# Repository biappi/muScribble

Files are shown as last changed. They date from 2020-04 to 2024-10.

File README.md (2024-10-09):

# µScribble

An hardware USB [Scribble Strip](https://www.sweetwater.com/insync/scribble-strip/)
 that supports the Mackie Control Protocol.

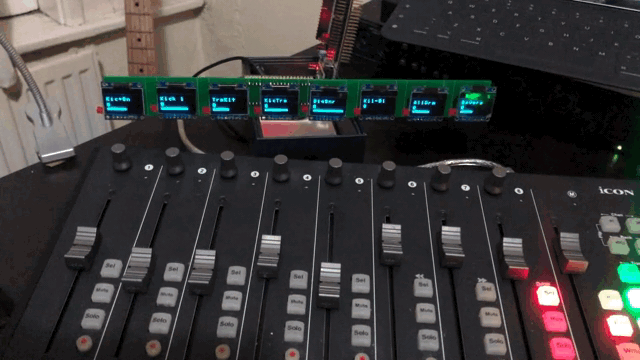
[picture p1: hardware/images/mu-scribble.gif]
µScribble in action


## Introduction

µScribble is an USB Midi gadget designed to be a companion to inexpensive faderboxes
without displays. It should be compatible with any DAW that supports control surfaces.
I've personally used it with [Apple Logic Pro](https://www.apple.com/logic-pro/) and
[Ableton Live](https://www.ableton.com/en/live/).

The hardware itself is very simple an d based around an
[STM32F4](https://www.st.com/en/microcontrollers-microprocessors/stm32f4-series.html)
evaluation board, sometimes known as "blackpill", while the displays are the SPI variant
of the ubiquitous [SSD1306 OLED screens](https://cdn-shop.adafruit.com/datasheets/SSD1306.pdf).

The software is implemented using the [unicore-mx](https://github.com/insane-adding-machines/unicore-mx)
fork of [libopencm3](https://github.com/libopencm3/libopencm3) as it has a slighlty
better support for the stm32 target platform. It should be relatively easy to port
the application code to any microcontroller of choice.

## Hardware design files

The hardware is designed using the [KiCad EDA](https://kicad.org)

* [KiCad project directory](hardware/kicad)
* [Schematic diagram PDF](hardware/images/schema.pdf)

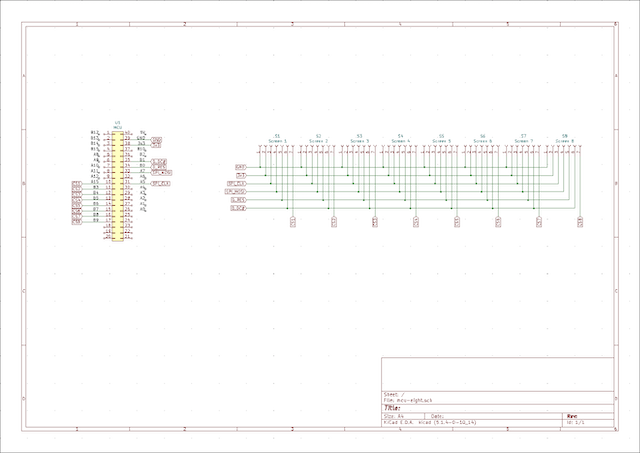
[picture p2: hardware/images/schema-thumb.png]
Schematic diagram thumbnail
  

* [Gerber fabrication files directory](hardware/gerbers)

  PCB diagram thumbnail

## Software

The firmware depends on the `arm-none-eabi-gcc` toolchain, and to compile it
it's sufficient to invoke

```
make
```

As a convenience, if you have the [STLink](https://github.com/stlink-org/stlink/)
tools installed, you can flash the firmware to the device using the `st-flash` command
with

```
make flash
```

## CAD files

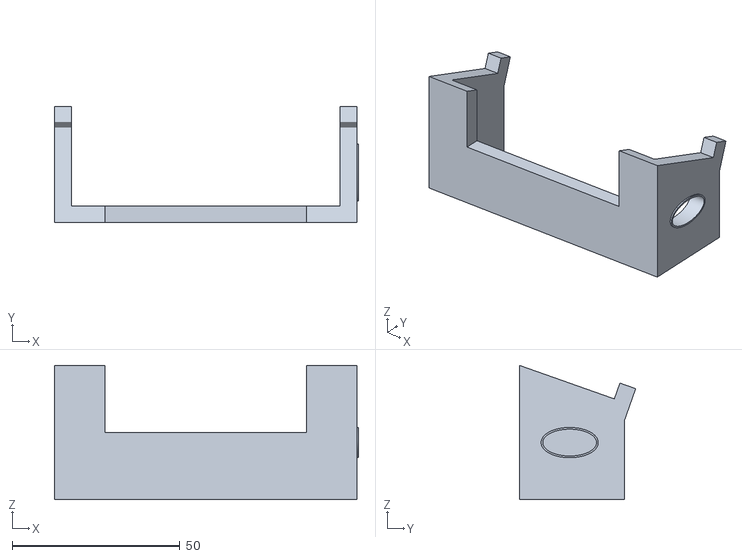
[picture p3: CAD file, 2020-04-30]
hardware/stl/holder.stl
90.5 x 34.7 x 40.0

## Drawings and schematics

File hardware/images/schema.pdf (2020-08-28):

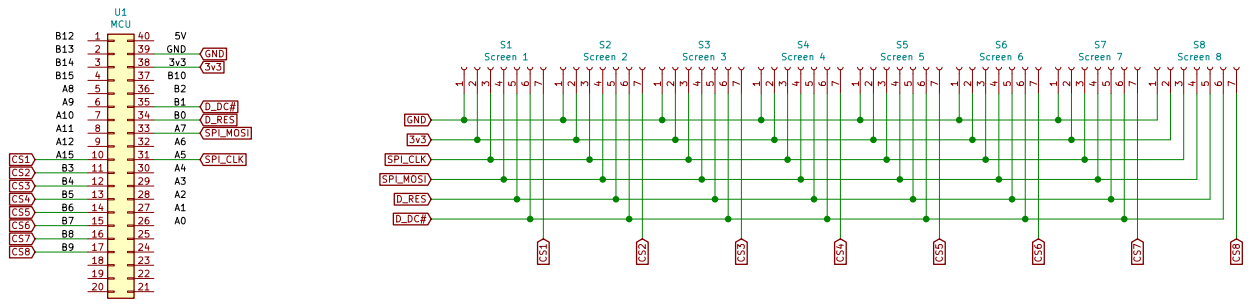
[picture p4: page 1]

File: mcu-eight.sch Sheet: /
Id: 1/1 Title:

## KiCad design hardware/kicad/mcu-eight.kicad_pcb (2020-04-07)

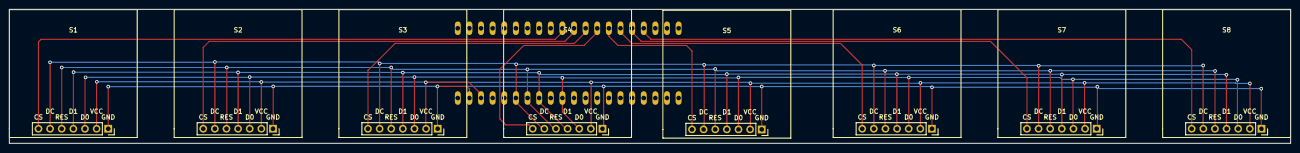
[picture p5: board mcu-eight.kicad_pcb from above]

Board: 2 copper layers, 280.0 x 29.3 mm, 9 parts (1 on the bottom side), 14 nets.

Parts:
S1: Screen 1; display-spi
S2: Screen 2; display-spi
S3: Screen 3; display-spi
S4: Screen 4; display-spi
S5: Screen 5; display-spi
S6: Screen 6; display-spi
S7: Screen 7; display-spi
S8: Screen 8; display-spi
U1: MCU; YAAJ_BohPill

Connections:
3v3: S1.2, S2.2, S3.2, S4.2, S5.2, S6.2, S7.2, S8.2, U1.38
CS1: S1.7, U1.10
CS2: S2.7, U1.11
CS3: S3.7, U1.12
CS4: S4.7, U1.13
CS5: S5.7, U1.14
CS6: S6.7, U1.15
CS7: S7.7, U1.16
CS8: S8.7, U1.17
D_DC#: S1.6, S2.6, S3.6, S4.6, S5.6, S6.6, S7.6, S8.6, U1.35
D_RES: S1.5, S2.5, S3.5, S4.5, S5.5, S6.5, S7.5, S8.5, U1.34
GND: S1.1, S2.1, S3.1, S4.1, S5.1, S6.1, S7.1, S8.1, U1.39
SPI_CLK: S1.3, S2.3, S3.3, S4.3, S5.3, S6.3, S7.3, S8.3, U1.31
SPI_MOSI: S1.4, S2.4, S3.4, S4.4, S5.4, S6.4, S7.4, S8.4, U1.33

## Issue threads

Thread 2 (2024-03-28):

Build errors on an m1 mac

iandoesallthethings, 2024-03-28:
I'm trying to flash this firmware onto a cheapo stm32f4 (weact brand? Not sure if it matters) but I'm getting stuck on the build step. I've been stumbling through getting all the dependencies squared away, but it seems like unicore-mx has some weird syntax errors. I've tried to debug it, but I'm pretty unfamiliar.

```bash
➜  muScribble git:(master) ✗ make flash
make -C unicore-mx TARGETS=stm32/f4 FP_FLAGS="-mfloat-abi=soft"
  GENHDR  include/unicore-mx/sam/3x/irq.json
  GENHDR  include/unicore-mx/sam/4l/irq.json
  GENHDR  include/unicore-mx/sam/3s/irq.json
  GENHDR  include/unicore-mx/sam/3a/irq.json
  GENHDR  include/unicore-mx/sam/3u/irq.json
  GENHDR  include/unicore-mx/sam/3n/irq.json
  GENHDR  include/unicore-mx/lpc17xx/irq.json
  GENHDR  include/unicore-mx/lpc13xx/irq.json
  GENHDR  include/unicore-mx/lpc43xx/m0/irq.json
  GENHDR  include/unicore-mx/lpc43xx/m4/irq.json
  GENHDR  include/unicore-mx/stm32/f4/irq.json
  GENHDR  include/unicore-mx/stm32/f3/irq.json
  GENHDR  include/unicore-mx/stm32/l4/irq.json
  GENHDR  include/unicore-mx/stm32/f2/irq.json
  GENHDR  include/unicore-mx/stm32/l0/irq.json
  GENHDR  include/unicore-mx/stm32/f0/irq.json
  GENHDR  include/unicore-mx/stm32/f7/irq.json
  GENHDR  include/unicore-mx/stm32/l1/irq.json
  GENHDR  include/unicore-mx/stm32/f1/irq.json
  GENHDR  include/unicore-mx/nrf/51/irq.json
  GENHDR  include/unicore-mx/nrf/52/irq.json
  GENHDR  include/unicore-mx/lm3s/irq.json
  GENHDR  include/unicore-mx/efm32/gg/irq.json
  GENHDR  include/unicore-mx/efm32/g/irq.json
  GENHDR  include/unicore-mx/efm32/lg/irq.json
  GENHDR  include/unicore-mx/efm32/tg/irq.json
  GENHDR  include/unicore-mx/vf6xx/irq.json
  BUILD   lib/stm32/f4
/bin/sh: -c: line 0: unexpected EOF while looking for matching `"'
/bin/sh: -c: line 1: syntax error: unexpected end of file
make[1]: *** [Makefile:70: lib/stm32/f4] Error 2
make: *** [Makefile:47: unicore-mx/lib/libucmx_stm32f4.a] Error 2
```

Any idea what's going wrong here?

iandoesallthethings, 2024-04-17:
Update: Trying it on debian 11 and getting the same errors, so I don't think it's a macos problem.

biappi, 2024-05-05:
hi! I'm having issues as well on my personal machine (an arm mac as well), albeit different ones... I think unicore-mx has a bit bit rotten over the years unfortunately :( I tried to quickly swap in libopencm3, but the usb stack is different enough that's not a direct recompilation.

I currently don't have much time to try and port this, but have you maybe looked into hacking the application code to work with an HAL library that works on your platform?  as long as you have midi input and spi output you should be able to hack something working

iandoesallthethings, 2024-05-06:
> but have you maybe looked into hacking the application code to work with an HAL library that works on your platform? as long as you have midi input and spi output you should be able to hack something working

Yeah, I'm interested in giving it a go! I'm pretty unfamiliar with this space (I'm a web dev by trade), so I'm unsure what to look for in a HAL. But if it's just a matter of replacing anything that uses unicore-mx with something else that does the same thing, I feel like I can probably figure it out.

My only other shortcut is to ask if you happen to have an old compiled binary laying around and hope my chip is similar enough lol

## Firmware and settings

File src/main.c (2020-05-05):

#include <stdbool.h>
#include <stdint.h>
#include <stdlib.h>
#include <string.h>
#include <stdio.h>

#include "platform.h"
#include "display.h"


#define MIN(a,b) (((a)<(b))?(a):(b))
#define MAX(a,b) (((a)>(b))?(a):(b))


char logic_peak_levels[8] = { 0 };
char logic_peak_offset[8] = { 0 };

char logic_control_strip[2][8][7] = { 0 };

uint8_t nibble_char(uint8_t x) {
    return (x < 10) ? ('0' + x) : ('a' + (x - 10));
}

void byte_string(char * string, uint8_t byte) {
    string[0]  = nibble_char((byte & 0xf0) >> 4);
    string[1]  = nibble_char((byte & 0x0f)     );
}

void send_small_dump(const uint8_t * buf, size_t len) {
    //                                   1     1
    //                         01234567890123456
    static uint8_t string[] = "00 00 00 00 00  ";

    for (int i = 0; i < 5; i++) {
        string[(i * 3)    ] = '-';
        string[(i * 3) + 1] = '-';
    }

    for (int i = 0; i < MIN(len, 5); i++) {
        byte_string(string + (i * 3), buf[i]);
    }


    display_send_string(string);
}
enum usb_midi_packet_types {
    usb_midi_sysex_start_or_continue = 0x04,
    usb_midi_sysex_ends_single_byte  = 0x05,
    usb_midi_sysex_ends_two_bytes    = 0x06,
    usb_midi_sysex_ends_three_bytes  = 0x07,
    usb_midi_channel_pressure        = 0x0d,
};


struct buffer {
    size_t  len;
    uint8_t buf[255];
};

struct sysex_parser {
    enum {
        sysex_parser_idle,
        sysex_parser_accumulating,
        sysex_parser_ended,
    } state;

    struct buffer sysex;
};

void sysex_parse(struct sysex_parser * parser, const uint8_t * packet)
{
    const uint8_t
    cable_id    = (packet[0] & 0xf0) >> 0;

    const enum usb_midi_packet_types
    packet_type = (packet[0] & 0x0f);

    struct buffer
    *sysex      = &(parser->sysex);

    switch (packet_type) {
        case usb_midi_sysex_start_or_continue:
            switch (parser->state) {
                case sysex_parser_idle:
                case sysex_parser_ended:
                    sysex->len = 0;
                    break;

                case sysex_parser_accumulating:
                    break;
            }

            sysex->buf[sysex->len++] = packet[1];
            sysex->buf[sysex->len++] = packet[2];
            sysex->buf[sysex->len++] = packet[3];
            parser->state = sysex_parser_accumulating;
            break;

        case usb_midi_sysex_ends_single_byte:
            sysex->buf[sysex->len++] = packet[1];
            parser->state = sysex_parser_ended;
            break;

        case usb_midi_sysex_ends_two_bytes:
            sysex->buf[sysex->len++] = packet[1];
            sysex->buf[sysex->len++] = packet[2];
            parser->state = sysex_parser_ended;
            break;

        case usb_midi_sysex_ends_three_bytes:
            sysex->buf[sysex->len++] = packet[1];
            sysex->buf[sysex->len++] = packet[2];
            sysex->buf[sysex->len++] = packet[3];
            parser->state = sysex_parser_ended;
            break;
    }
}


void usb_midi_received_callback(const uint8_t * buf, size_t len)
{
    static struct sysex_parser parser = { 0 };

    for (int i = 0; i < len / 4; i++) {
        const uint8_t 
        *packet = buf + (i * 4);

        const uint8_t
        cable_id    = (packet[0] & 0xf0) >> 0;

        const enum usb_midi_packet_types
        packet_type = (packet[0] & 0x0f);

        switch (packet_type) {
            case usb_midi_channel_pressure: {
                const uint8_t level   = (packet[2] & 0x0f);
                const uint8_t channel = (packet[2] & 0x70) >> 4;
                logic_peak_levels[channel] = level;
                logic_peak_offset[channel] = 0;
                break;
            }
        }

        sysex_parse(&parser, packet);

        if (parser.state == sysex_parser_ended) {
            const uint8_t * midiData = parser.sysex.buf;

            parser.state = sysex_parser_idle;

            if (
                (midiData[0] == 0xf0) &&
                (midiData[5] == 0x12)
            ) {
                const uint8_t  offset =  midiData[6];
                const uint8_t *src    = &midiData[7];
                      uint8_t *dst    = (((uint8_t *)logic_control_strip) + offset);

                while (*src != 0xf7) {
                    *dst++ = *src++;
                }
            }
        }

    }
}

// - //

void draw_peak_levels(uint8_t t)
{
    #define bar_size 128

    uint8_t data[bar_size] = { 0 };

    int l = logic_peak_levels[t];
    int e = 0;

    if (l) {
        l = MIN(l, 0xc);

        e = (l * 128) / 12 - logic_peak_offset[t];
        logic_peak_offset[t] -= 8;
        if (e < 0) {
            e = 0;
            logic_peak_levels[t] = 0;
        }
    }

    for (int i = 0; i < bar_size; i++) {
        bool    is_on     = (i < e);
        bool    is_odd    = ((i % 2) == 0);
        bool    tick      = ((i % 4) == 0);
        bool    tick_mask = 0x3c;

        uint8_t mark      = 0x00; // tick ? 0x42 : 0x00;
        uint8_t border    = 0x81;
        uint8_t dot       = is_on && is_odd ? 0xff : 0x00;

        data[i] = dot | border;
    }

    display_send_data(data, bar_size);

}

void draw_logic_strip()
{
    for (int t = 0; t < 8; t++) {
        display_select(display_selection_1 + t);

        display_goto_line_column(0, 0);

        for (int i = 0; i < 7; i++) {
            display_send_2x_character_top(logic_control_strip[0][t][i]);
        }

        display_goto_line_column(1, 0);

        for (int i = 0; i < 7; i++) {
            display_send_2x_character_bottom(logic_control_strip[0][t][i]);
        }

        display_goto_line_column(3, 0);

        for (int i = 0; i < 7; i++) {
            display_send_2x_character_top(logic_control_strip[1][t][i]);
        }

        display_goto_line_column(4, 0);

        for (int i = 0; i < 7; i++) {
            display_send_2x_character_bottom(logic_control_strip[1][t][i]);
        }

        display_goto_line_column(6, 0);
        draw_peak_levels(t);
    }
}

void draw_at_startup()
{
    display_select(display_selection_all);
    display_goto_line_column(0, 0);

    for (
        display_selection_t s = display_selection_1;
        s <= display_selection_8;
        s++
    ) {
        //               01234567
        char string[] = "DISP    ";
        string[4] = s - display_selection_1 + '1';
        display_select(s);

        char *s;

        s = string;
        while (*s != 0) {
            display_send_2x_character_top(*s++);
        }

        s = string;
        while (*s != 0) {
            display_send_2x_character_bottom(*s++);
        }
    }
}

int main(void)
{
    platform_init();
    draw_at_startup();

    const uint32_t jiffies_mult = 30; // redraw every N jiffies_mult

    while (1) {
        uint32_t poll_time = platform_jiffies();

        draw_logic_strip();

        uint32_t after_draw = platform_jiffies();
        
        {
            display_select(display_selection_8);
            display_goto_line_column(6, 0);

            char buffer[8];
            snprintf(buffer, sizeof(buffer), "%d", after_draw - poll_time);
            display_send_string(buffer);
        }

        for (int i = 0; i < jiffies_mult; i++) {
            do {
                platform_poll();
                WFI();
            } while(poll_time == platform_jiffies());
        }
    }

}

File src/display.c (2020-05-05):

#include "display.h"
#include "platform-private.h"

#include <stdlib.h>
#include <stdint.h>
#include <string.h>

#include <unicore-mx/stm32/rcc.h>
#include <unicore-mx/stm32/gpio.h>

extern const unsigned char font[256][8];

#define WIDTH 128
#define PIXEL_HEIGHT 64
#define HEIGHT (PIXEL_HEIGHT / 8)

#define SSD1306_MEMORYMODE                           0x20
#define SSD1306_COLUMNADDR                           0x21
#define SSD1306_PAGEADDR                             0x22
#define SSD1306_SETCONTRAST                          0x81
#define SSD1306_CHARGEPUMP                           0x8D
#define SSD1306_SEGREMAP                             0xA0
#define SSD1306_DISPLAYALLON_RESUME                  0xA4
#define SSD1306_DISPLAYALLON                         0xA5
#define SSD1306_NORMALDISPLAY                        0xA6
#define SSD1306_INVERTDISPLAY                        0xA7
#define SSD1306_SETMULTIPLEX                         0xA8
#define SSD1306_DISPLAYOFF                           0xAE
#define SSD1306_DISPLAYON                            0xAF
#define SSD1306_COMSCANINC                           0xC0
#define SSD1306_COMSCANDEC                           0xC8
#define SSD1306_SETDISPLAYOFFSET                     0xD3
#define SSD1306_SETDISPLAYCLOCKDIV                   0xD5
#define SSD1306_SETPRECHARGE                         0xD9
#define SSD1306_SETCOMPINS                           0xDA
#define SSD1306_SETVCOMDETECT                        0xDB
#define SSD1306_SETLOWCOLUMN                         0x00
#define SSD1306_SETHIGHCOLUMN                        0x10
#define SSD1306_SETSTARTLINE                         0x40
#define SSD1306_RIGHT_HORIZONTAL_SCROLL              0x26
#define SSD1306_LEFT_HORIZONTAL_SCROLL               0x27
#define SSD1306_VERTICAL_AND_RIGHT_HORIZONTAL_SCROLL 0x29
#define SSD1306_VERTICAL_AND_LEFT_HORIZONTAL_SCROLL  0x2A
#define SSD1306_DEACTIVATE_SCROLL                    0x2E
#define SSD1306_ACTIVATE_SCROLL                      0x2F
#define SSD1306_SET_VERTICAL_SCROLL_AREA             0xA3

void display_send_data(const uint8_t *buf, const size_t len)
{
    display_transport_set_data();

    for (int i = 0; i < len; i++)
        display_transport_write(buf[i]);
}

static inline void display_send_cmd(uint8_t cmd)
{
    display_transport_set_control();
    display_transport_write(cmd);
}

static inline void display_send_cmd1(uint8_t cmd, uint8_t arg1)
{
    display_transport_set_control();
    display_transport_write(cmd);
    display_transport_write(arg1);
}

static inline void display_send_cmd2(uint8_t cmd, uint8_t arg1, uint8_t arg2)
{
    display_transport_set_control();
    display_transport_write(cmd);
    display_transport_write(arg1);
    display_transport_write(arg2);
}

void display_send_character(char c) {
    display_send_data(font[c], 8);
}

void display_send_2x_width_character(char c) {
    const uint8_t *glyph = font[c];
    uint8_t doubled[8 * 2];

    for (int i = 0; i < 8; i++) {
        uint8_t line = glyph[i];

        uint8_t top_line = line;

        doubled[(i * 2)    ] = top_line;
        doubled[(i * 2) + 1] = top_line;
    }
    
    display_send_data(doubled, 16);
}

void display_send_2x_character_top(char c) {
    const uint8_t *glyph = font[c];
    uint8_t doubled[8 * 2];

    for (int i = 0; i < 8; i++) {
        uint8_t line = glyph[i];

        uint8_t top_line = 
            ((line & 0x01)     ) |
            ((line & 0x01) << 1) |
            ((line & 0x02) << 1) |
            ((line & 0x02) << 2) |
            ((line & 0x04) << 2) |
            ((line & 0x04) << 3) |
            ((line & 0x08) << 3) |
            ((line & 0x08) << 4) 
        ;

        doubled[(i * 2)    ] = top_line;
        doubled[(i * 2) + 1] = top_line;
    }
    
    display_send_data(doubled, 16);
}

void display_send_2x_character_bottom(char c) {
    const uint8_t *glyph = font[c];
    uint8_t doubled[8 * 2];

    for (int i = 0; i < 8; i++) {
        uint8_t line = glyph[i];

        uint8_t top_line = 
            ((line & 0x10) >> 4) | 
            ((line & 0x10) >> 3) |
            ((line & 0x20) >> 3) |
            ((line & 0x20) >> 2) |
            ((line & 0x40) >> 2) |
            ((line & 0x40) >> 1) |
            ((line & 0x80) >> 1) |
            ((line & 0x80)     ) 
        ;

        doubled[(i * 2)    ] = top_line;
        doubled[(i * 2) + 1] = top_line;
    }
    
    display_send_data(doubled, 16);
}

void display_send_string(const char *string) {
    while (*string != 0)
        display_send_character(*string++);
}

void display_send_empty_line(void) {
    uint8_t test[32] = {0x00};
    display_send_data(test, sizeof(test));
    display_send_data(test, sizeof(test));
    display_send_data(test, sizeof(test));
    display_send_data(test, sizeof(test));
}

void display_send_empty_screen(void) {
    display_goto_line_column(0, 0);
    for (int i = 0; i < 8; i++)
        display_send_empty_line();
}

void display_goto_line_column(int line, int column) {
    display_send_cmd2(SSD1306_PAGEADDR, line & 0x0f, 0xff);
    display_send_cmd2(SSD1306_COLUMNADDR, column & 0x7f, WIDTH - 1);
}

void display_init(void) {
    display_send_cmd(SSD1306_DISPLAYOFF);
    display_send_cmd1(SSD1306_CHARGEPUMP, 0x14);
    display_send_cmd1(SSD1306_MEMORYMODE, 0x00);
    display_send_empty_screen();
    display_send_cmd(SSD1306_DISPLAYON);
}

void display_select_all() {
    gpio_clear(GPIOA, DISP_CS_PORTA);
    gpio_clear(GPIOB, DISP_CS_PORTB);
}

void display_select_none() {
    gpio_set(GPIOA, DISP_CS_PORTA);
    gpio_set(GPIOB, DISP_CS_PORTB);
}

void display_select(display_selection_t s) {
    switch(s) {
        case display_selection_1:
            display_select_none();
            gpio_clear(GPIOA, DISP_CS1);
            break;

        case display_selection_2:
            display_select_none();
            gpio_clear(GPIOB, DISP_CS2);
            break;

        case display_selection_3:
            display_select_none();
            gpio_clear(GPIOB, DISP_CS3);
            break;

        case display_selection_4:
            display_select_none();
            gpio_clear(GPIOB, DISP_CS4);
            break;

        case display_selection_5:
            display_select_none();
            gpio_clear(GPIOB, DISP_CS5);
            break;

        case display_selection_6:
            display_select_none();
            gpio_clear(GPIOB, DISP_CS6);
            break;

        case display_selection_7:
            display_select_none();
            gpio_clear(GPIOB, DISP_CS7);
            break;

        case display_selection_8:
            display_select_none();
            gpio_clear(GPIOB, DISP_CS8);
            break;

        case display_selection_all:
            display_select_all();
            break;

        case display_selection_none:
            display_select_none();
            break;
    }
}
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

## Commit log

2019-10-28 adding an spi-screen test
2019-10-30 fixing display and font orientation
    [display.c, main.c]
2019-11-01 correctly unframing sysex messages and parsing the logic control strip
    [main.c]
2020-04-07 adding the pcb kicad project file
    [mcu-eight-B_Cu.gbr, mcu-eight-B_Mask.gbr, mcu-eight-B_SilkS.gbr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]
2020-04-21 updated pin configuration for the board, and implement display CS selection
2020-04-21 add a phony target to flash the device
2020-04-22 adding functions to print double size fonts
2020-04-30 adding a tentative 3d printer holder
    [holder.stl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]
2020-05-04 change the first display to avoid a stale character during updates
    [main.c]
2020-05-05 add a way to invert the display
    [display.c]
2024-10-09 Update README.md
    https://forum.kicad.info/t/warning-avoid-all-links-to-kicad-pcb-org-use-kicad-org/31521
